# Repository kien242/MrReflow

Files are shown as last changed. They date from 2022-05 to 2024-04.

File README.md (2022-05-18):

Invent This, Invent That

# ESPReflow
Firmware for SMT reflow controller.

> **!!! WARNING: This project deals with mains power and high current !!!**
> Please be careful if you wish to replicate any of it's functionality and never work on a PCB or any open wires that are connected to the mains !
> Author has no responsibility for your safety and wellbeing, so please take care of yourself.

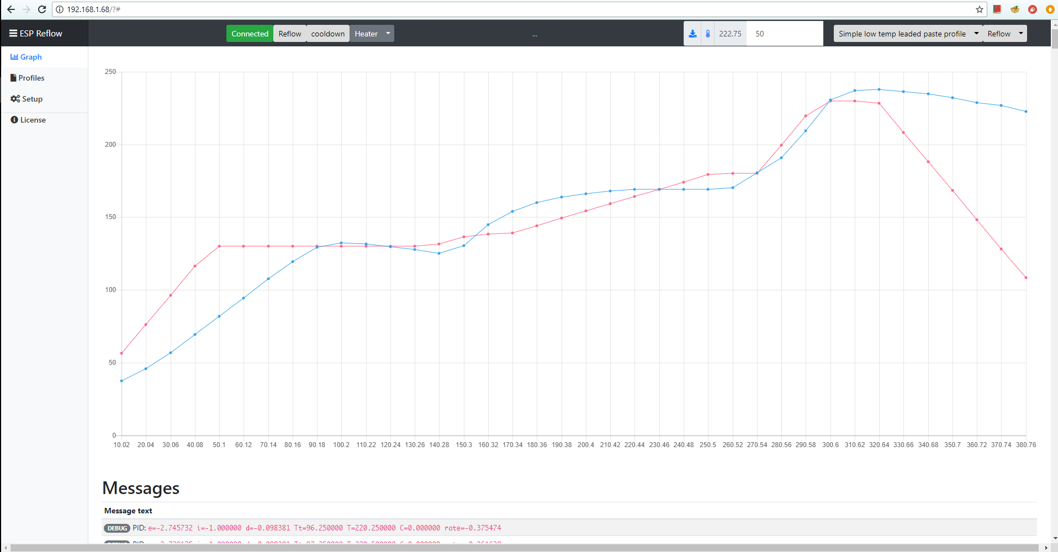
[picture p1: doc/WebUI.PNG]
ESPReflow Web UI


# How it works
The purpose of this project is to control a heater of any sort to facilitate SMT reflow soldering utilizing a predefined temperature profile. Control of the heater is performed by ESP8266 or ESP32 chip via Web UI over WiFi.

To achieve that, readings from a thermocouple are used for closed loop temperature control of the target board. The controller does it's best to follow a preconfigured temperature profile for a particular SMT soldering. Of course the accuracy of the temperature profile achieved is heavily dependant on the thermal properties of the heating element, environment, the boards, etc. The controller tries to compensate for that by the means of a PID controller which has to be tuned to a particular setup.

## Prototype Hardware

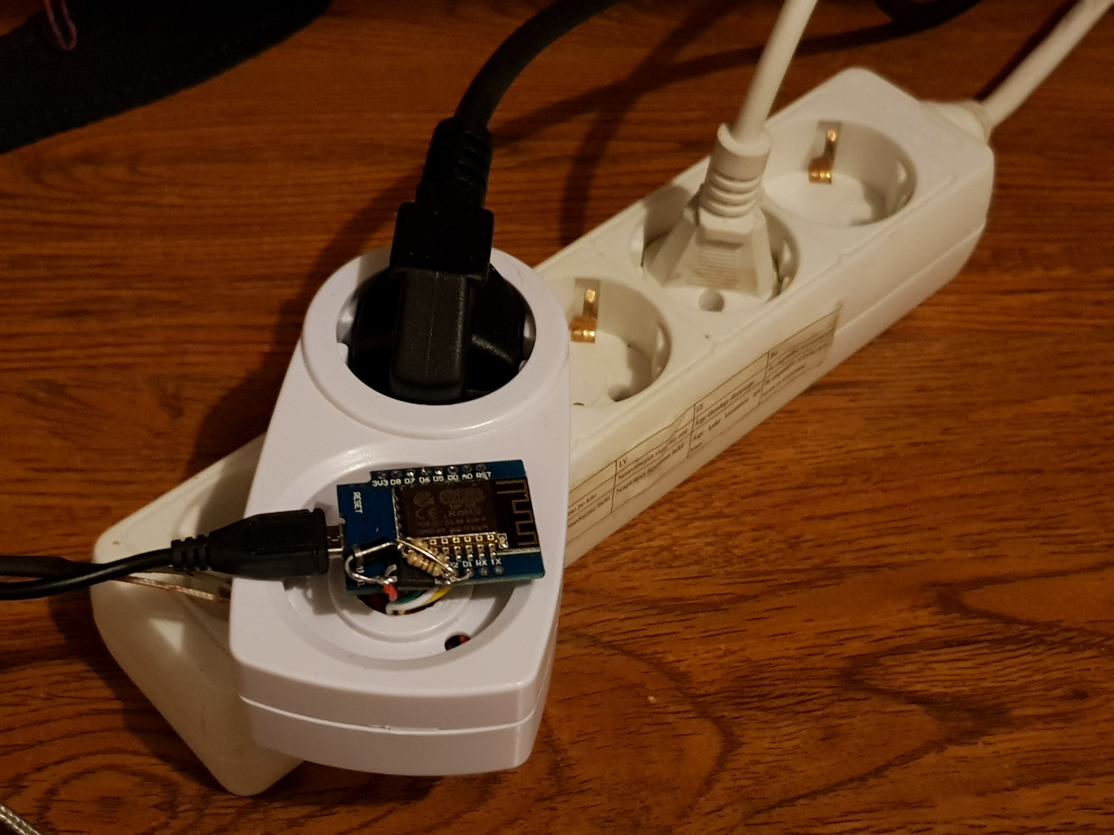
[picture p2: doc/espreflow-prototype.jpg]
ESPReflow prototype


* Some generic mechanical timer enclosure is used for the plug, socket and, well, enclosure.
* max6675 is used for interfacing with a thermocouple.
* Generic optopair is used for controlling a 10A relay (for the prototype).
* Weemos D1 mini is used for the brains.
* Some cheap 1200W IR Hotplate is used for the load
* a peace of prototype board is used for dummy board

## Schematics

ESReflow schematics
rev 1.0 board

EasyEDA project page: https://easyeda.com/andrius.mikonis/ESPReflow-f4c523157afa47758e46728248cdb19b

## Assigned pins

```
#define thermoDO 13 // D7
#define thermoCS 12 // D6
#define thermoCLK 14 // D5
#define relay 4 // D2
```

## Building
### Angular Frontend

Angular front end source is in `web-src-angular` folder and should be built using nodejs. After binaries are built,
they should be gzipped and copied into `data/web` folder before uploading.

### Backend

Backend is implemented using Arduino SDK and built using PlatformIO. Before building, please copy `src/sample_wificonfig.h`
to `src/wificonfig.h` and add default Wireless Network configuration. You will be able to edit this configuration via Web interface later.

## Modes of operation
### Reflow

In this mode the controller will perform reflow algorithm following selected reflow profile.
Controller will turn off the mode once the temperature reaches safe values after the profile is completed.

### Calibrate

In this mode a selected calibration algorithm will be used to find optimal PID controller parameters.
Controller will turn off the mode once the temperature reaches safe values after the calibration is completed.

### Keep Target

In this mode the controller will reach and maintain target temperature. Useful to check PID configuration. `default` PID configuration will be used in this mode.

# Flashing

There are two ways to flash the controller - via serial or via OTA.

## Serial

Find `RX/TX/GND` pins on the board, connect your serial adapter and flash either Arduino, PlatformIO or whatever flasher you like.
**NOTE: `RX/TX` pins are NOT 5V tolerant. Please use 3.3V serial adapter or level shifter from 5V**

## OTA

When the controller is first turned on it creates an AP with the name `ESPReflow` and the ip address `192.168.4.1`. Connect to the controller, wait until the page loads and go to `Setup`, enter WiFi SSID and credentials. Save the configuration and reboot.
After this is done it will connect to the specified WiFi AP and will register it's own domain as `ReflowControl.local`.
Tuning and operation of the controller can then be done.

## OTA HTTP upload

You can upload a firmware binary using `Setup` - just upload the new firmware on the WebUI.

# Usage

## Connect your hotplate/oven

### Hot plate

### IR Hot plate
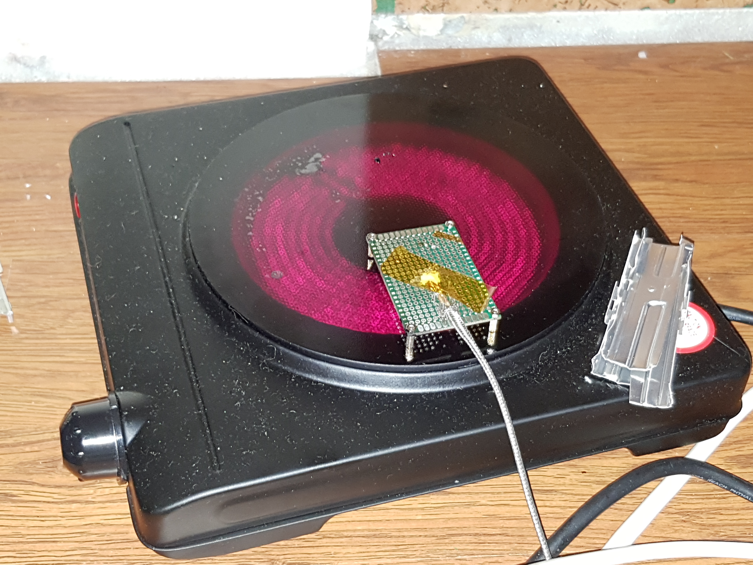
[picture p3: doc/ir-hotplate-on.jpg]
IR hotplate in action


## K-type thermal probe

Thermocouple must be placed on a dummy board, that would approximately resemble the target boards. For best results that board must be placed in a similar matter as the target board. Furthermore, since hotplates do not heat evenly(even some ovens), care must be taken to allow dummy board be heated the same way as the target board(i.e. it must be placed approximately the same distance and orientation as the target board in respect to the heating elements). Otherwise you may burn the target board.

## PID tuning

PID tuning must be done for every heating device individually. You can do it by trial and error, or ESPReflow can do it for you. There are several auto tuning algorithms available (a slightly modified [PID-aTune library fork](https://github.com/t0mpr1c3/Arduino-PID-AutoTune-Library)):

*		ZIEGLER_NICHOLS_PI
*		ZIEGLER_NICHOLS_PID
*		TYREUS_LUYBEN_PI
*		TYREUS_LUYBEN_PID
*		CIANCONE_MARLIN_PI
*		CIANCONE_MARLIN_PID
*		AMIGOF_PI
*		PESSEN_INTEGRAL_PID
*		SOME_OVERSHOOT_PID
*		NO_OVERSHOOT_PID"

## Reflow profile

# Problem Solving

## Unable to properly tune IR Hot plate

During development a cheap IR hot plate was used. I found that if you place your temperature probe and the boards on the hot plate itself it would be very hard to control the temperature of the board properly. So, I used aluminium raisers, that raise the board around 5-10mm from the hot plate so that IR radiation would heat the boards instead of the glass plate.

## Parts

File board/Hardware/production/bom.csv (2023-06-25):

Designator | Footprint | Quantity | Value | LCSC Part #
C1, C4 | 0603 | 2 | 1u
C10, C6, C8, C9 | 0603 | 4 | 100n
C11, C7 | 0603 | 2 | 10n
C12, C15 | 0603 | 2 | 10uF
C13, C14 | 0603 | 2 | 100nF
C2, C3 | CP_Elec_4x5.4 | 2 | 10u
C5 | CP_EIA-3216-12_Kemet-S_Pad1.58x1.35mm_HandSolder | 1
D1 | D_SOD-123 | 1 | 1N5819
H1, H2, H3, H4 | MountingHole_3.2mm_M3_Pad | 4 | MountingHole_Pad
J1 | TerminalBlock_4Ucon_1x02_P3.50mm_Horizontal | 1 | VIN
J2 | USB-C-16pin-hight-v2 | 1
J3 | 1.14_TFT_Display | 1 | Conn_01x08
J4 | TerminalBlock_4Ucon_1x02_P3.50mm_Horizontal | 1 | TC1
J5 | TerminalBlock_4Ucon_1x02_P3.50mm_Horizontal | 1 | TC2
J6 | TerminalBlock_4Ucon_1x02_P3.50mm_Horizontal | 1 | SSR1
J7 | TerminalBlock_4Ucon_1x02_P3.50mm_Horizontal | 1 | SSR2
J8 | TerminalBlock_4Ucon_1x02_P3.50mm_Horizontal | 1 | SSR3
JP1, JP2 | SolderJumper-3_P2.0mm_Open_TrianglePad1.0x1.5mm_NumberLabels | 2
L1, L2, L3, L4 | 0603 | 4 | ferrite
LS1 | Buzzer_12x9.5RM7.6 | 1 | Speaker
Q1 | SOT-23_Handsoldering | 1 | AO3407
Q2, Q3, Q4 | TO-252-2 | 3 | IRLR2905Z
Q5 | SOT-23_Handsoldering | 1 | BSS138
Q7, Q8 | SOT-23_Handsoldering | 2 | 2N3904
R1 | 0603 | 1 | 100K
R10, R11 | 0603 | 2 | R_Small
R12 | 0603 | 1 | ??
R13, R14, R15, R16, R2, R24, R25, R3, R4, R5, R6, R7 | 0603 | 12 | 10k
R17, R18 | 0603 | 2 | 5k1
R19 | 0603 | 1 | 22k1
R20 | 0603 | 1 | 47k5
R21, R23 | 0603 | 2 | 22r
R22 | 0603 | 1 | 1k
R8, R9 | 0603 | 2 | 5k
SW1, SW2 | SW_PUSH_6mm_H13mm | 2
SW3 | SW_SPST_B3U-1000P | 1 | SW_RESET
SW4 | SW_SPST_B3U-1000P | 1 | SW_BOOT
SW5 | RotaryEncoder_Alps_EC11E-Switch_Vertical_H20mm | 1
U1 | YAAJ_DCDC_StepDown_LM2596 | 1 | YAAJ_DCDC_StepDown_LM2596
U2 | SOT-223-3_TabPin2 | 1 | NCP1117-3.3_SOT223
U3 | QFN-28-1EP_5x5mm_P0.5mm_EP3.35x3.35mm_ThermalVias | 1 | CP2102-GM
U4, U6 | SOIC-8_3.9x4.9mm_P1.27mm | 2 | MAX31855KASA
U5 | ESP32-WROOM-32 | 1 | ESP32-WROOM-32

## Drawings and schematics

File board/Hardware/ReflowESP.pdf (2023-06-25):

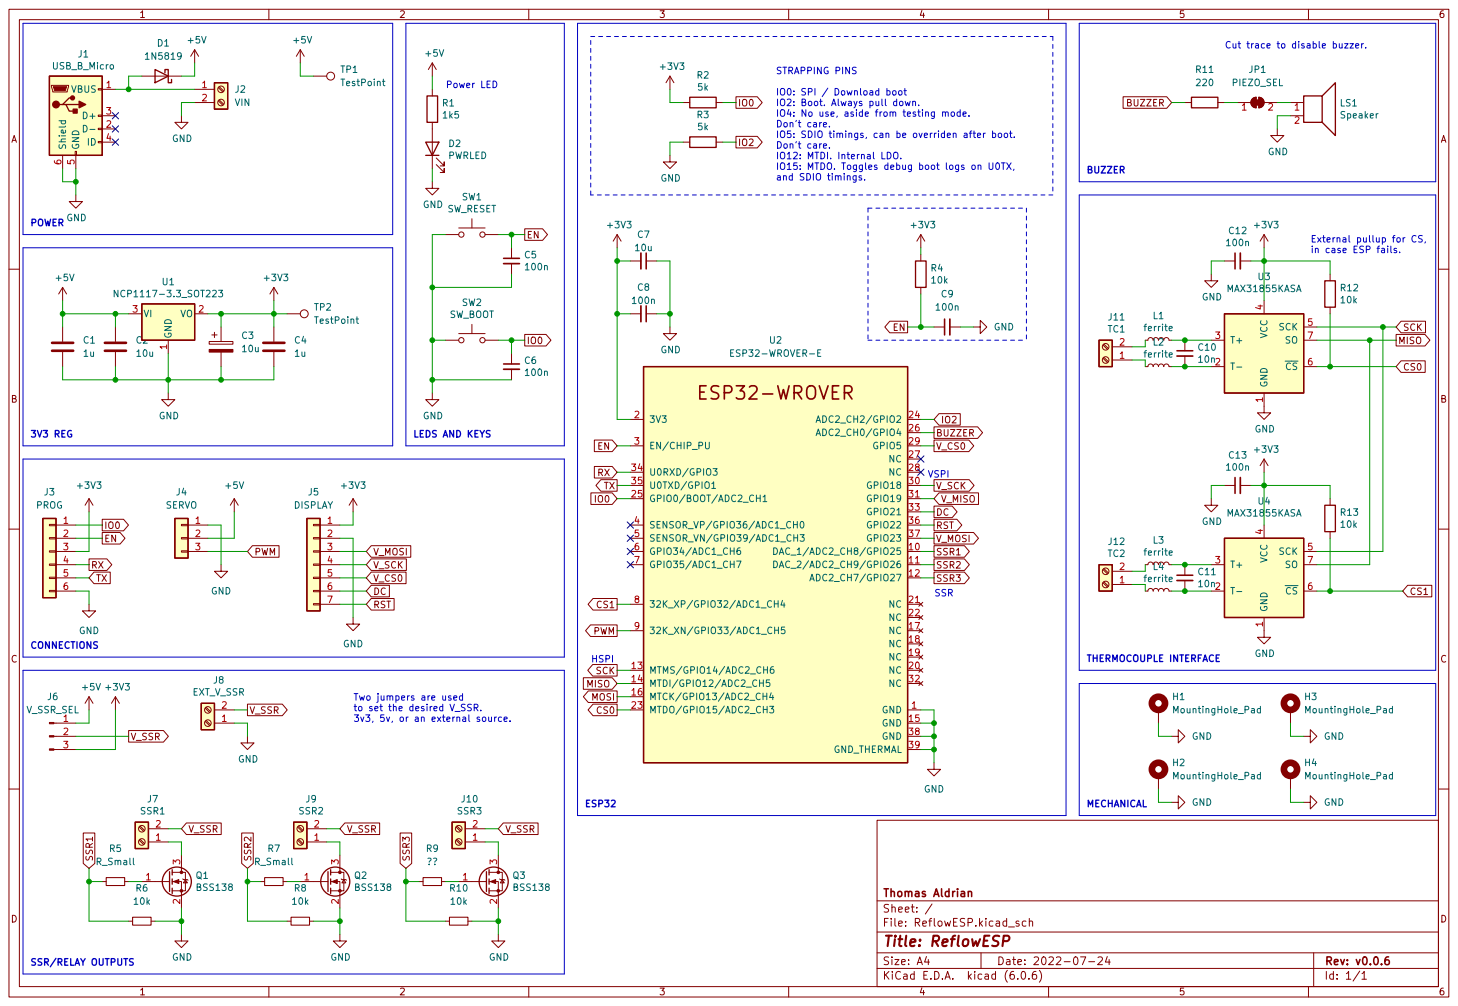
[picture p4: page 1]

Cut trace to disable buzzer. BUZZER
JP1 PIEZO_SEL GND
LS1 Speaker GND

IO0: SPI / Download boot
IO2: Boot. Always pull down.
IO4: No use, aside from testing mode. Don't care.

IO5: SDIO timings, can be overriden after boot. Don't care.

IO12: MTDI. Internal LDO.
IO15: MTDO. Toggles debug boot logs on U0TX,

External pullup for CS,

1 VO 2 VI 3 U1 NCP1117-3.3_SOT223 GND GND þÿESP32--WROVER

to set the desired V_SSR. 3v3, 5v, or an external source. CONNECTIONS

Two jumpers are used

File: ReflowESP.kicad_sch Sheet: / Thomas Aldrian

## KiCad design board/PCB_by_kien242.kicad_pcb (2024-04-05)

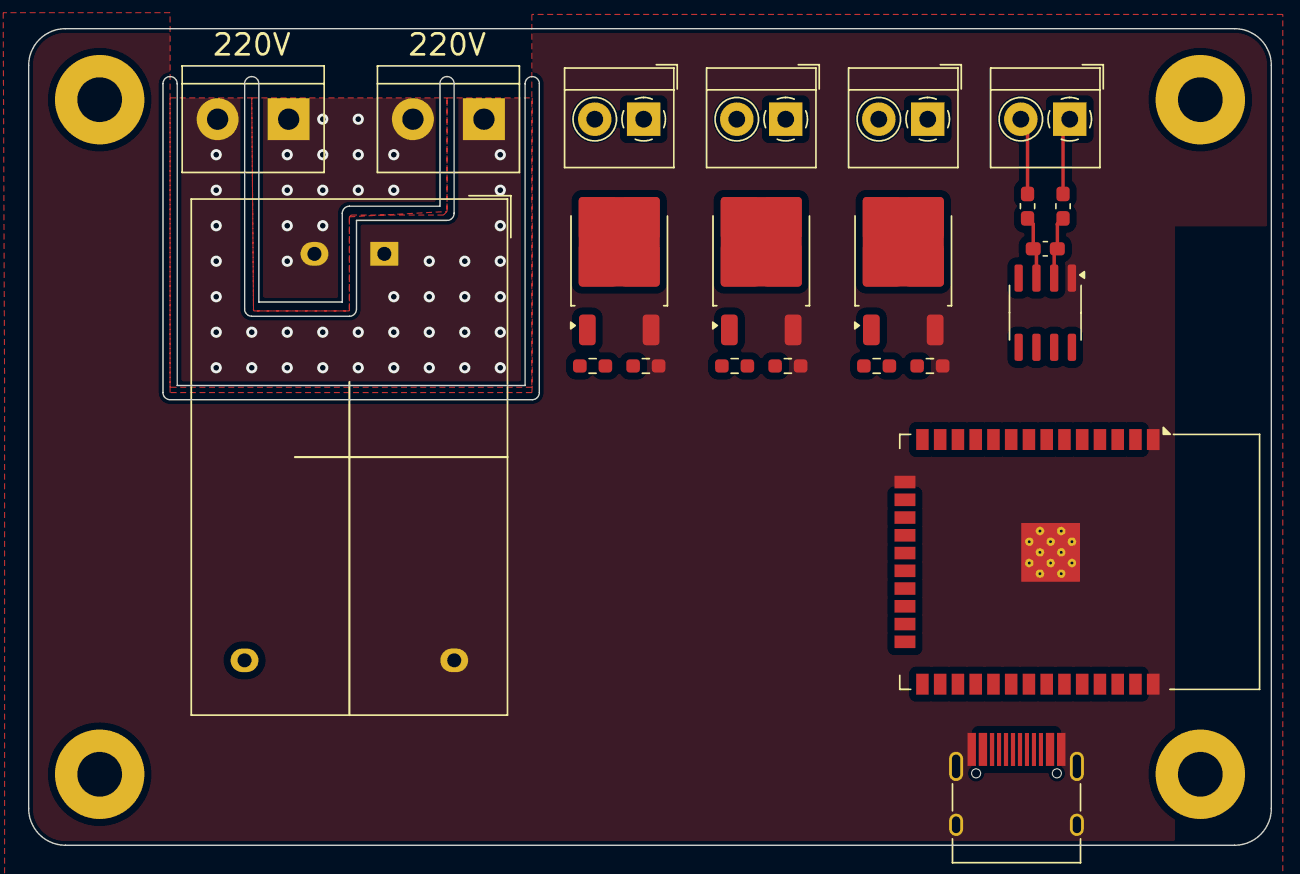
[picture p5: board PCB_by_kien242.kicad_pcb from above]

Board: 2 copper layers, 88.9 x 58.4 mm, 26 parts (0 on the bottom side), 24 nets.

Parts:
C11: 10n; C_0603_1608Metric_Pad1.08x0.95mm_HandSolder
H1, H2, H3, H4: MountingHole_Pad; MountingHole_3.2mm_M3_Pad
J1, J3: VIN; TerminalBlock_bornier-2_P5.08mm
J2: USB-C-16pin-hight-v2
J4: TC1; TerminalBlock_4Ucon_1x02_P3.50mm_Horizontal
J6: SSR1; TerminalBlock_4Ucon_1x02_P3.50mm_Horizontal
J7: SSR2; TerminalBlock_4Ucon_1x02_P3.50mm_Horizontal
J8: SSR3; TerminalBlock_4Ucon_1x02_P3.50mm_Horizontal
L1, L2: ferrite; L_0603_1608Metric_Pad1.05x0.95mm_HandSolder
PS1: HLK-PM05; Converter_ACDC_Hi-Link_HLK-PMxx
Q4, Q5, Q6: IRLR2905Z; TO-252-2
R19, R20: R_Small; R_0603_1608Metric_Pad0.98x0.95mm_HandSolder
R21: ??; R_0603_1608Metric_Pad0.98x0.95mm_HandSolder
R22, R23, R24: 10k; R_0603_1608Metric_Pad0.98x0.95mm_HandSolder
U4: MAX31855KASA; SOIC-8_3.9x4.9mm_P1.27mm
U5: ESP32-WROOM-32

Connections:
+3.3V: U4.4 (VCC), U5.2 (VDD)
CS0: U4.6 (~CS), U5.23 (IO15)
D+: J2.A6 (D+), J2.B6 (D+)
D-: J2.A7 (D-), J2.B7 (D-)
GND: J2.A1 (GND), J2.A12 (GND), J2.B1 (GND), J2.B12 (GND), J2.S1 (SHIELD), PS1.3 (-Vout), Q4.3 (S), Q5.3 (S), Q6.3 (S), R22.2, R23.2, R24.2, U4.1 (GND), U5.1 (GND), U5.15 (GND), U5.38 (GND), U5.39 (GND)
MISO: U4.7 (SO), U5.14 (IO12)
unnamed: J1.1, J3.2, PS1.1 (AC/L)
unnamed: J1.2, J3.1, PS1.2 (AC/N)
unnamed: J4.1, L2.2
unnamed: J4.2, L1.2
unnamed: J6.1, Q4.2 (D)
unnamed: J7.1, Q5.2 (D)
unnamed: J8.1, Q6.2 (D)
unnamed: Q4.1 (G), R19.2
unnamed: Q5.1 (G), R20.2
unnamed: Q6.1 (G), R21.2
unnamed: C11.1, L1.1, U4.3 (T+)
unnamed: C11.2, L2.1, U4.2 (T-)
SCK: U4.5 (SCK), U5.13 (IO14)
SSR1: R21.1, R24.1, U5.10 (IO25)
SSR2: R20.1, R23.1, U5.11 (IO26)
SSR3: R19.1, R22.1, U5.12 (IO27)
VBUS: J2.A4 (VBUS), J2.A9 (VBUS), J2.B4 (VBUS), J2.B9 (VBUS)
V_SSR: J6.2, J7.2, J8.2, PS1.4 (+Vout)

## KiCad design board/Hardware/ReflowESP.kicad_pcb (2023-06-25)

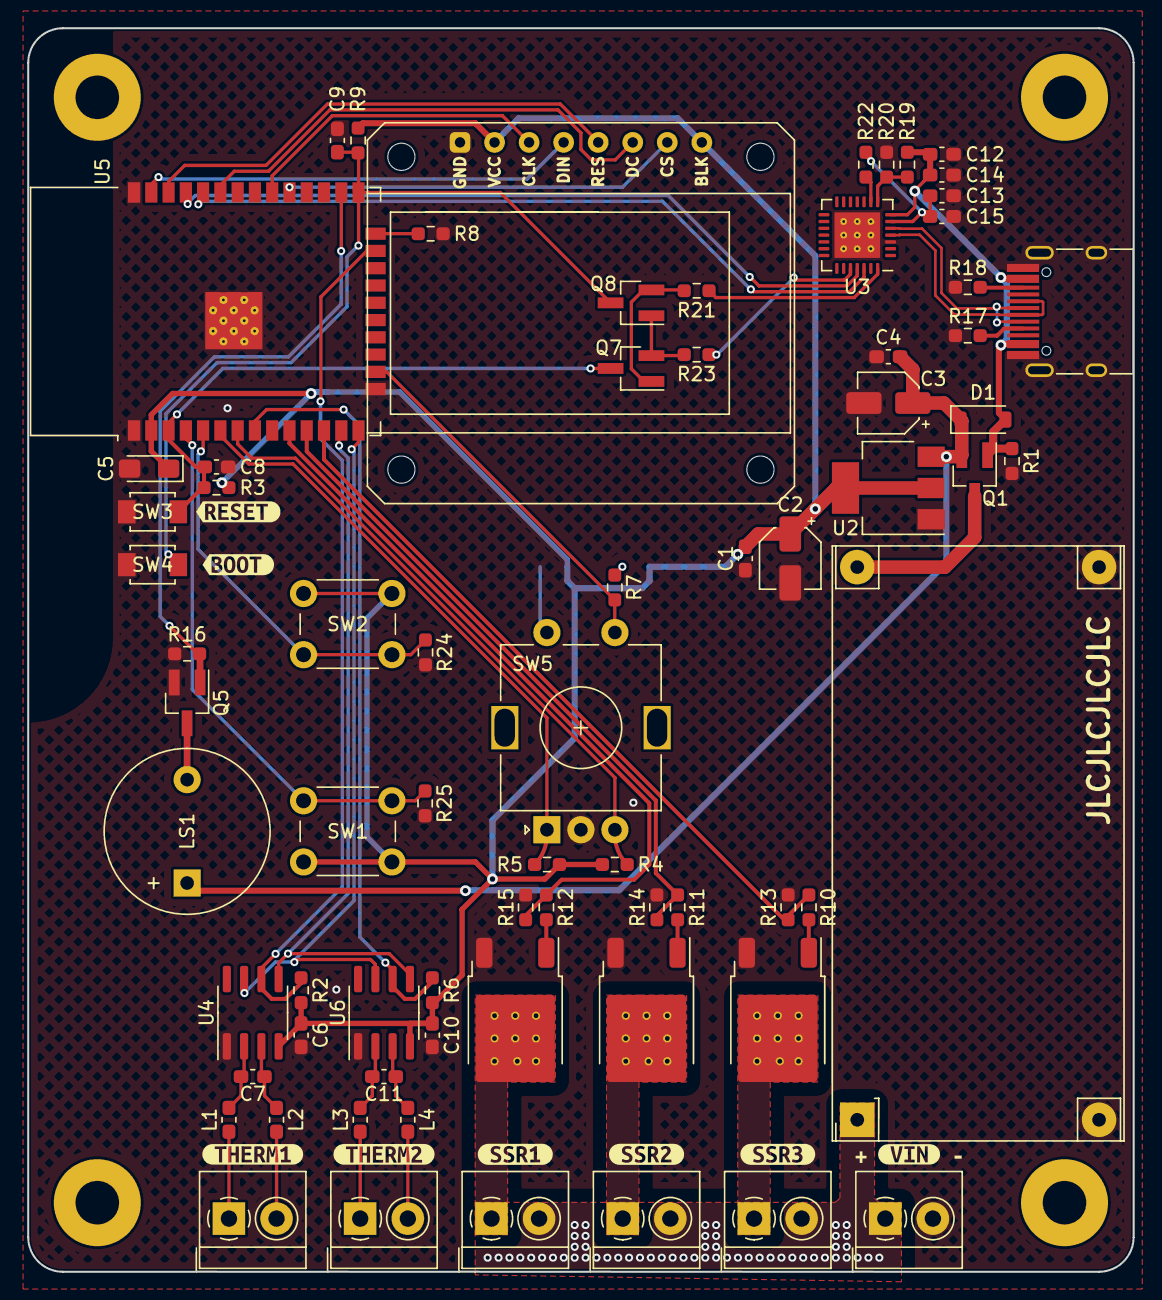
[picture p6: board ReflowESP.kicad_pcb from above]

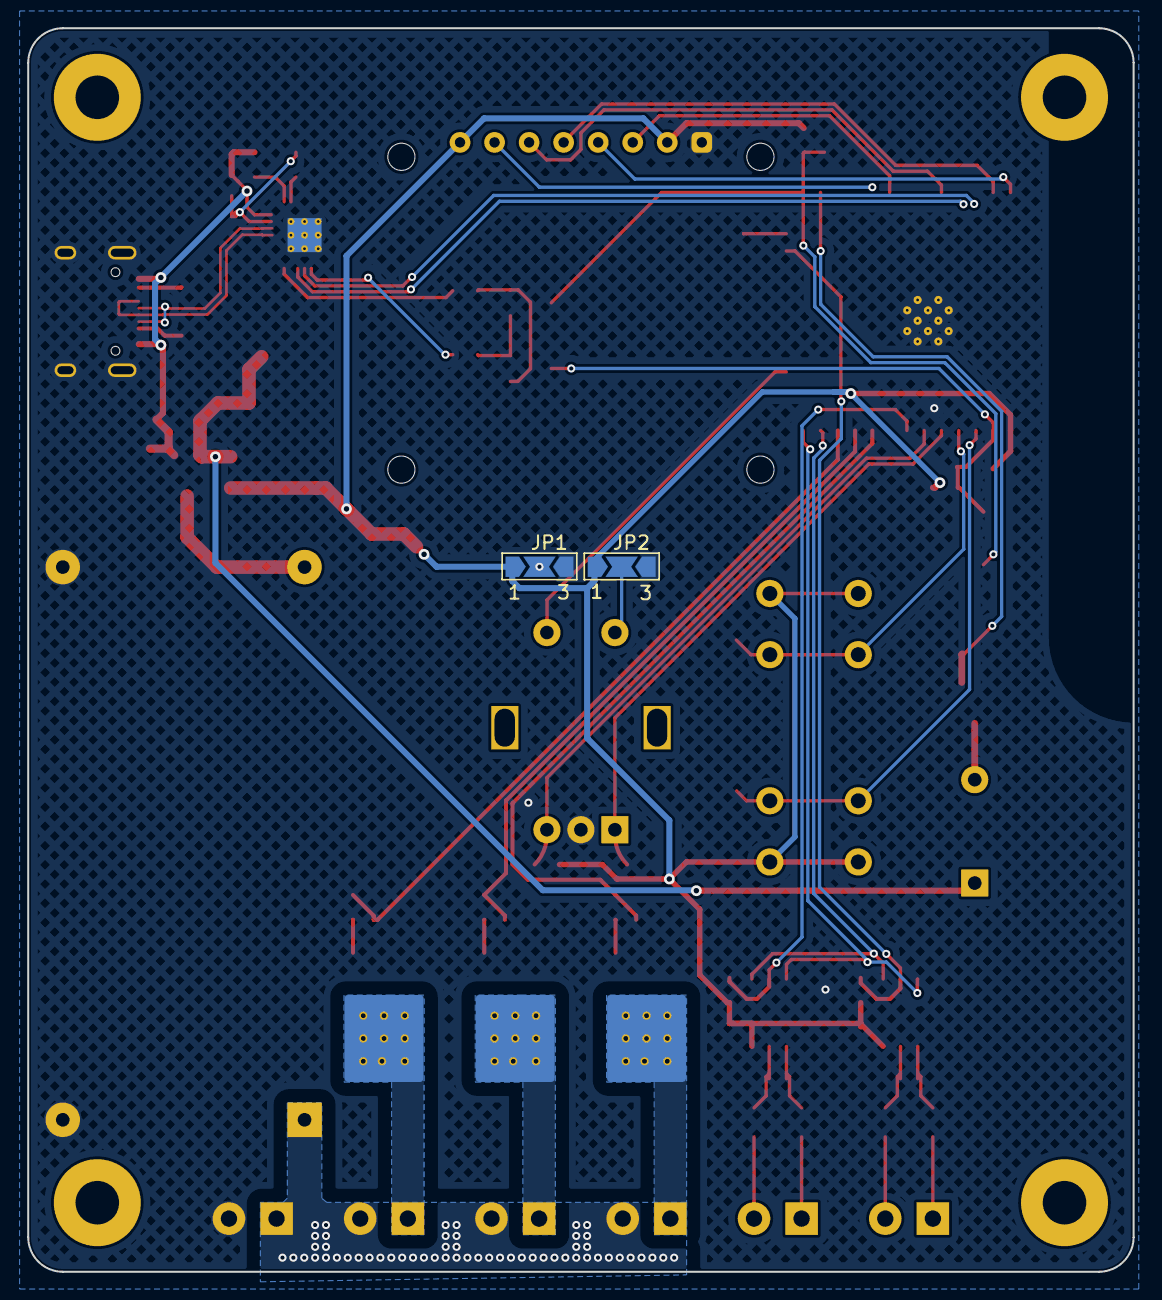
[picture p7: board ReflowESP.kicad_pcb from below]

Board: 2 copper layers, 81.3 x 91.4 mm, 88 parts (2 on the bottom side), 57 nets.

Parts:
C1, C4: 1u; C_0603_1608Metric_Pad1.08x0.95mm_HandSolder
C2, C3: 10u; CP_Elec_4x5.4
C5: CP_EIA-3216-12_Kemet-S_Pad1.58x1.35mm_HandSolder
C6, C8, C9, C10: 100n; C_0603_1608Metric_Pad1.08x0.95mm_HandSolder
C7, C11: 10n; C_0603_1608Metric_Pad1.08x0.95mm_HandSolder
C12, C15: 10uF; C_0603_1608Metric_Pad1.08x0.95mm_HandSolder
C13, C14: 100nF; C_0603_1608Metric_Pad1.08x0.95mm_HandSolder
D1: 1N5819; D_SOD-123
H1, H2, H3, H4: MountingHole_Pad; MountingHole_3.2mm_M3_Pad
J1: VIN; TerminalBlock_4Ucon_1x02_P3.50mm_Horizontal
J2: USB-C-16pin-hight-v2
J3: Conn_01x08; 1.14_TFT_Display
J4: TC1; TerminalBlock_4Ucon_1x02_P3.50mm_Horizontal
J5: TC2; TerminalBlock_4Ucon_1x02_P3.50mm_Horizontal
J6: SSR1; TerminalBlock_4Ucon_1x02_P3.50mm_Horizontal
J7: SSR2; TerminalBlock_4Ucon_1x02_P3.50mm_Horizontal
J8: SSR3; TerminalBlock_4Ucon_1x02_P3.50mm_Horizontal
JP1, JP2: SolderJumper-3_P2.0mm_Open_TrianglePad1.0x1.5mm_NumberLabels
L1, L2, L3, L4: ferrite; L_0603_1608Metric_Pad1.05x0.95mm_HandSolder
LS1: Speaker; Buzzer_12x9.5RM7.6
Q1: AO3407; SOT-23_Handsoldering
Q2, Q3, Q4: IRLR2905Z; TO-252-2
Q5: BSS138; SOT-23_Handsoldering
Q7, Q8: 2N3904; SOT-23_Handsoldering
R1: 100K; R_0603_1608Metric_Pad0.98x0.95mm_HandSolder
R2, R3, R4, R5, R6, R7, R13, R14, R15, R16, R24, R25: 10k; R_0603_1608Metric_Pad0.98x0.95mm_HandSolder
R8, R9: 5k; R_0603_1608Metric_Pad0.98x0.95mm_HandSolder
R10, R11: R_Small; R_0603_1608Metric_Pad0.98x0.95mm_HandSolder
R12: ??; R_0603_1608Metric_Pad0.98x0.95mm_HandSolder
R17, R18: 5k1; R_0603_1608Metric_Pad0.98x0.95mm_HandSolder
R19: 22k1; R_0603_1608Metric_Pad0.98x0.95mm_HandSolder
R20: 47k5; R_0603_1608Metric_Pad0.98x0.95mm_HandSolder
R21, R23: 22r; R_0603_1608Metric_Pad0.98x0.95mm_HandSolder
R22: 1k; R_0603_1608Metric_Pad0.98x0.95mm_HandSolder
SW1, SW2: SW_PUSH_6mm_H13mm
SW3: SW_RESET; SW_SPST_B3U-1000P
SW4: SW_BOOT; SW_SPST_B3U-1000P
SW5: RotaryEncoder_Alps_EC11E-Switch_Vertical_H20mm
U1: YAAJ_DCDC_StepDown_LM2596
U2: NCP1117-3.3_SOT223; SOT-223-3_TabPin2
U3: CP2102-GM; QFN-28-1EP_5x5mm_P0.5mm_EP3.35x3.35mm_ThermalVias
U4, U6: MAX31855KASA; SOIC-8_3.9x4.9mm_P1.27mm
U5: ESP32-WROOM-32
kibuzzard-6465B1A6: G***; kibuzzard-6465B1A6
kibuzzard-6465B1D4: G***; kibuzzard-6465B1D4
kibuzzard-6465B1DF: G***; kibuzzard-6465B1DF
kibuzzard-6465FE6A: G***; kibuzzard-6465FE6A
kibuzzard-6465FE70: G***; kibuzzard-6465FE70
kibuzzard-64660A1B: G***; kibuzzard-64660A1B
kibuzzard-64660A10: G***; kibuzzard-64660A10
kibuzzard-64660AB6: G***; kibuzzard-64660AB6
kibuzzard-64660ABC: G***; kibuzzard-64660ABC
kibuzzard-646609E4: G***; kibuzzard-646609E4

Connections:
+3.3V: C1.2, C2.1, C5.1, C6.1, C10.1, J3.2, J3.8, JP1.1 (A), JP2.1 (A), R2.2, R3.1, R4.1, R5.2, R6.2, R9.1, SW1.2, SW2.1, U2.2 (VO), U4.4 (VCC), U5.2 (VDD), U6.4 (VCC)
+5V: C3.1, C4.2, D1.1 (K), LS1.1, Q1.2 (S), U2.3 (VI)
BUZZER: Q5.1 (G), R16.2, U5.26 (IO4)
CS0: R2.1, U4.6 (~CS), U5.23 (IO15)
CS1: R6.1, U5.8 (IO32), U6.6 (~CS)
D+: J2.A6 (D+), J2.B6 (D+), U3.4 (D+)
D-: J2.A7 (D-), J2.B7 (D-), U3.5 (D–)
DC: J3.6, U5.33 (IO21)
DTR: R21.1, U3.28 (~DTR)
EN: C8.1, Q7.3 (C), R3.2, SW3.2, U5.3 (EN)
GND: C1.1, C2.2, C3.2, C4.1, C5.2, C6.2, C8.2, C9.2, C10.2, C12.1, C13.2, C14.2, C15.1, J1.2, J2.A1 (GND), J2.A12 (GND), J2.B1 (GND), J2.B12 (GND), J2.S1 (SHIELD), J3.1, JP1.3 (B), JP2.3 (B), Q2.3 (S), Q3.3 (S), Q4.3 (S), Q5.2 (S), R1.2, R8.2, R13.2, R14.2, R15.2, R16.1, R17.1, R18.1, R20.2, R24.2, R25.2, SW3.1, SW4.1, SW5.C, U1.2 (GND), U1.3 (GND), U2.1 (GND), U3.3 (GND), U3.29 (GND), U4.1 (GND), U5.1 (GND), U5.15 (GND), U5.38 (GND), U5.39 (GND), U6.1 (GND)
IO0: C9.1, Q8.3 (C), R9.2, SW4.2, U5.25 (IO0)
IO2: R8.1, U5.24 (IO2)
MISO: U4.7 (SO), U5.14 (IO12), U6.7 (SO)
unnamed: J2.A5 (CC1), R17.2
unnamed: J2.B5 (CC2), R18.2
unnamed: J4.1, L1.1
unnamed: J4.2, L2.2
unnamed: J5.1, L3.1
unnamed: J5.2, L4.2
unnamed: J6.1, Q2.2 (D)
unnamed: J7.1, Q3.2 (D)
unnamed: J8.1, Q4.2 (D)
unnamed: JP1.2 (C), R7.1
unnamed: JP2.2 (C), SW5.S1
unnamed: Q1.3 (D), U1.4 (Vout)
unnamed: Q2.1 (G), R10.2
unnamed: Q3.1 (G), R11.2
unnamed: Q4.1 (G), R12.2
unnamed: LS1.2, Q5.3 (D)
unnamed: Q7.1 (B), Q8.2 (E), R21.2
unnamed: Q7.2 (E), Q8.1 (B), R23.2
unnamed: R22.2, U3.9 (~RST)
unnamed: C7.1, L2.1, U4.3 (T+)
unnamed: C7.2, L1.2, U4.2 (T-)
unnamed: C11.1, L4.1, U6.3 (T+)
unnamed: C11.2, L3.2, U6.2 (T-)
RE_A: R5.1, SW5.A, U5.6 (IO34)
RE_B: R4.2, SW5.B, U5.7 (IO35)
RE_SW: R7.2, SW5.S2, U5.16 (IO13)
RST: J3.5, U5.36 (IO22)
RTS: R23.1, U3.24 (~RTS)
RX: U3.26 (TXD), U5.34 (RXD0/IO3)
SCK: U4.5 (SCK), U5.13 (IO14), U6.5 (SCK)
SSR1: R12.1, R15.1, U5.10 (IO25)
SSR2: R11.1, R14.1, U5.11 (IO26)
SSR3: R10.1, R13.1, U5.12 (IO27)
SW_1: R25.1, SW1.1, U5.4 (SENSOR_VP)
SW_2: R24.1, SW2.2, U5.5 (SENSOR_VN)
TX: U3.25 (RXD), U5.35 (TXD0/IO1)
VBUS: C12.2, C14.1, D1.2 (A), J2.A4 (VBUS), J2.A9 (VBUS), J2.B4 (VBUS), J2.B9 (VBUS), Q1.1 (G), R1.1, R19.1, U3.7 (REGIN)
VBUSREF: R19.2, R20.1, U3.8 (VBUS)
VCC: C13.1, C15.2, R22.1, U3.6 (VDD)
V_CS0: J3.7, U5.29 (IO5)
V_MOSI: J3.4, U5.37 (IO23)
V_SCK: J3.3, U5.30 (IO18)
V_SSR: J1.1, J6.2, J7.2, J8.2, U1.1 (Vin)

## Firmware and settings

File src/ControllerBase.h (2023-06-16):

/**
 *  Copyright (C) 2018  foxis (Andrius Mikonis <andrius.mikonis@gmail.com>)
 *
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
 *  You should have received a copy of the GNU General Public License
 *  along with this program.  If not, see <http://www.gnu.org/licenses/>.
 **/

#ifndef CONTROLLER_BASE_H
#define CONTROLLER_BASE_H

#include <PID_v10.h>
#include <SPI.h>
#include "Config.h"
#include <PID_AutoTune_v0.h> // https://github.com/t0mpr1c3/Arduino-PID-AutoTune-Library
#include <Adafruit_GFX.h>
#include <Adafruit_SSD1306.h>


#define thermoDO 12
#define thermoCS 15
#define thermoCLK 14

#define DEFAULT_TARGET 60
#define MAX_ON_TIME 1000 * 60 * 15
#define MAX_TEMPERATURE 400
#define MIN_TEMP_RISE_TIME 1000 * 120
#define MIN_TEMP_RISE 10
#define CONTROL_HYSTERISIS .01
#define DEFAULT_TEMP_RISE_AFTER_OFF 30.0
#define SAFE_TEMPERATURE 50
#define CAL_HEATUP_TEMPERATURE 90
#define DEFAULT_CAL_ITERATIONS 3
#define WATCHDOG_TIMEOUT 30000

#include <max6675.h>


#define CB_GETTER(T, name) \
  virtual T name() { return _##name; }
#define CB_SETTER(T, name) \
  virtual T name(T name)   \
  {                        \
    T pa##name = _##name;  \
    _##name = name;        \
    return pa##name;       \
  }

class ControllerBase
{
public:
  typedef float Temperature_t;
  typedef enum
  {
    UNKNOWN = -100,
    INIT = -2,
    ERROR_OFF = -1,
    OFF = 0,
    ON = 1,
    TARGET_PID = 2,
    CALIBRATE = 3,
    REFLOW = 4,
    CALIBRATE_COOL = 5,
    REFLOW_COOL = 6,
  } MODE_t;

  typedef std::function<void(const char *message)> THandlerFunction_Message;
  typedef std::function<void(MODE_t last, MODE_t current)> THandlerFunction_Mode;
  typedef std::function<void(const char *stage, float target)> THandlerFunction_Stage;
  typedef std::function<void(bool heater)> THandlerFunction_Heater;
  typedef std::function<void(const std::vector<Temperature_t> &readings, unsigned long now)> THandlerFunction_ReadingsReport;

private:
  std::vector<Temperature_t> _readings;
  double _temperature;
  double _target;
  double _CALIBRATE_max_temperature;
  double _target_control;
  double _avg_rate;
  unsigned long _last_heater_on;

  unsigned long _now;

  double _calP, _calD, _calI;

protected:
  Config &config;

private:
  PID pidTemperature;
  PID_ATune aTune;

public:
  ControllerBase(Config &cfg, Adafruit_SSD1306 &display);
  Adafruit_SSD1306 display;
  String line1 = "";
  String line2 = "";
  String line3 = "";

  void draw()
  {
    display.clearDisplay();
    display.setCursor(0, 0);
    display.setTextSize(1);
    display.println(line1);

    display.setCursor(0, 12);
    display.setTextSize(4);
    display.println(line2);

    if (line3.length() > 10)
    {
      display.setTextSize(1);
    }
    else
    {
      display.setTextSize(2);
    }
    display.setCursor(0, 64 - 16);

    display.println(line3);

    if (_heater)
    {
      display.fillCircle(120, 7, 5, 1);
    }
    else
    {
      display.drawCircle(120, 7, 5, 1);
    }

    int state = millis() / 100 % 4;
    display.setCursor(118, 54);
    if (state == 0)
    {
      display.println("-");
    }
    if (state == 1)
    {
      display.println("\\");
    }
    if (state == 2)
    {
      display.println("|");
    }
    if (state == 3)
    {
      display.println("/");
    }
    display.display();
  }

  virtual const char *name() = 0;

  virtual void loop(unsigned long now);

  CB_GETTER(double, target)
  CB_SETTER(double, target)

  CB_GETTER(double, temperature)

  CB_GETTER(std::vector<Temperature_t> &, readings)

  CB_GETTER(MODE_t, mode)
  CB_SETTER(MODE_t, mode)

  CB_GETTER(bool, heater)

  CB_GETTER(bool, locked)
  CB_SETTER(bool, locked)

  CB_GETTER(unsigned long, start_time)

  CB_SETTER(const String &, profile)
  CB_GETTER(const String &, profile)

  CB_SETTER(double, avg_rate)
  CB_GETTER(double, avg_rate)

  CB_GETTER(const String &, stage)

  CB_SETTER(THandlerFunction_Message, onMessage)
  CB_SETTER(THandlerFunction_Mode, onMode)
  CB_SETTER(THandlerFunction_Heater, onHeater)
  CB_SETTER(THandlerFunction_Stage, onStage)
  CB_SETTER(THandlerFunction_ReadingsReport, onReadingsReport)

  PID &setPID(float P, float I, float D);

  PID &setPID(const String &name);

  void resetPID();

  String calibrationString();

  const char *translate_mode(MODE_t mode = UNKNOWN);

  Temperature_t temperature_to_log(float t);

  float log_to_temperature(Temperature_t t);

  float measure_temperature(unsigned long now);
  unsigned long elapsed(unsigned long now);

private:
  MAX6675 thermocouple;
  bool _locked;
  bool _heater;
  bool _last_heater;
  unsigned long last_m;
  unsigned long last_log_m;
  unsigned long _start_time;

  void _setPinMode(int pin, int mode);
  void _setPinValue(int pin, int value);

  float _read_temperature();

  MODE_t _mode;
  MODE_t _last_mode;

  String _profile;
  String _stage;

protected:
  CB_SETTER(const String &, stage)
  CB_SETTER(double, temperature)

  THandlerFunction_Message _onMessage;
  THandlerFunction_Mode _onMode;
  THandlerFunction_Heater _onHeater;
  THandlerFunction_Stage _onStage;
  THandlerFunction_ReadingsReport _onReadingsReport;

  void callMessage(const char *format, ...);

  void reportReadings(unsigned long now);

  virtual void handle_mode(unsigned long now);

  virtual void handle_measure(unsigned long now);

  virtual void handle_safety(unsigned long now);

  virtual void handle_pid(unsigned long now);

  virtual void handle_reflow(unsigned long now) = 0;

  virtual void handle_calibration(unsigned long now);
};

#endif

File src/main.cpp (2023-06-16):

/**
 *  Copyright (C) 2018  foxis (Andrius Mikonis <andrius.mikonis@gmail.com>)
 *
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
 *  You should have received a copy of the GNU General Public License
 *  along with this program.  If not, see <http://www.gnu.org/licenses/>.
 **/

#include <ESPAsyncWebServer.h>
#include <SPIFFSEditor.h>
#include "ReflowController_v1.h"
#include <ArduinoJson.h>
#include "AsyncJson.h"
#include "Config.h"
#include <Adafruit_GFX.h>
#include <Adafruit_SSD1306.h>
#include <esp_task_wdt.h>

#define OLED_RESET 4        // Reset pin # (or -1 if sharing Arduino reset pin)
#define SCREEN_ADDRESS 0x3D ///< See datasheet for Address; 0x3D for 128x64, 0x3C for 128x32

AsyncWebServer server(80);
AsyncWebSocket ws("/ws");
AsyncEventSource events("/event");
ControllerBase *controller = NULL;
AsyncWebSocketClient *_client = NULL;
Config config("/config.json", "/profiles.json");
Adafruit_SSD1306 display(128, 64, &Wire, -1);

void textThem(const char *text)
{
  int tryId = 0;
  for (int count = 0; count < ws.count();)
  {
    if (ws.hasClient(tryId))
    {
      ws.client(tryId)->text(text);
      count++;
    }
    tryId++;
  }
}

void textThem(const String &text)
{
  textThem(text.c_str());
}

void textThem(JsonObject &root, AsyncWebSocketClient *client)
{
  String json;
  root.printTo(json);

  if (client != NULL)
    client->text(json);
  else
    textThem(json);
}

void textThem(JsonObject &root)
{
  textThem(root, NULL);
}

void send_reading(float reading, float target, float time, AsyncWebSocketClient *client, bool reset)
{
  S_printf("Sending readings...");

  StaticJsonBuffer<200> jsonBuffer;
  JsonObject &root = jsonBuffer.createObject();

  JsonObject &data = root.createNestedObject("readings");
  JsonArray &times = root.createNestedArray("times");
  JsonArray &readings = root.createNestedArray("readings");
  JsonArray &targets = root.createNestedArray("targets");

  times.add(time);
  readings.add(reading);
  targets.add(target);
  data["reset"] = reset;

  textThem(root);
}

void setupController(ControllerBase *c)
{
  S_printf("Controller setup..");

  // report messages
  c->onMessage([](const char *msg)
               {
		StaticJsonBuffer<200> jsonBuffer;
		JsonObject &root = jsonBuffer.createObject();
		root["message"] = msg;
		textThem(root); });

  c->onHeater([](bool heater)
              {
		S_printf("Heater: %s", heater ? "on" : "off");
		StaticJsonBuffer<200> jsonBuffer;
		JsonObject &root = jsonBuffer.createObject();
		root["heater"] = heater;
		textThem(root); });

  // report readings
  c->onReadingsReport([](const std::vector<ControllerBase::Temperature_t> &readings, unsigned long elapsed)
                      { send_reading(controller->log_to_temperature(readings[readings.size() - 1]), controller->target(), elapsed / 1000.0, NULL, readings.size() == 1); });

  // report mode change
  c->onMode([](ControllerBase::MODE_t last, ControllerBase::MODE_t current)
            {
		S_printf("Change mode: from %s to %s", controller->translate_mode(last), controller->translate_mode(current));
		StaticJsonBuffer<200> jsonBuffer;
		JsonObject &root = jsonBuffer.createObject();
		root["mode"] = controller->translate_mode(current);

		textThem(root); });
  c->onStage([](const char *stage, float target)
             {
		S_printf("Reflow stage: %s", stage);
		StaticJsonBuffer<200> jsonBuffer;
		JsonObject &root = jsonBuffer.createObject();
		root["stage"] = stage;
		root["target"] = target;
		textThem(root); });

  controller = c;
  S_printf("Controller setup DONE");
}

void send_data(AsyncWebSocketClient *client)
{
  S_printf("Sending all data...");
  std::vector<ControllerBase::Temperature_t>::iterator I = controller->readings().begin();
  std::vector<ControllerBase::Temperature_t>::iterator end = controller->readings().end();
  DynamicJsonBuffer jsonBuffer;
  JsonObject &root = jsonBuffer.createObject();
  JsonArray &times = root.createNestedArray("times");
  JsonArray &readings = root.createNestedArray("readings");
  JsonArray &targets = root.createNestedArray("targets");
  root["reset"] = true;
  root["message"] = "INFO: Connected!";
  root["mode"] = controller->translate_mode();
  root["target"] = controller->target();
  root["profile"] = controller->profile();
  root["stage"] = controller->stage();
  root["heater"] = controller->heater();

  float seconds = 0;
  while (I != end)
  {
    times.add(seconds);
    readings.add(controller->log_to_temperature(*I));
    targets.add(controller->target());
    seconds += config.reportInterval / 1000.0;
    I++;
  }

  textThem(root, client);
}

void setup()
{
  Serial.begin(115200);
  Wire.begin(I2C_SCL, I2C_SDA, 100000);
  pinMode(18, OUTPUT);
  pinMode(23, OUTPUT);
  SPIFFS.begin();

  if (!display.begin(SSD1306_SWITCHCAPVCC, SCREEN_ADDRESS))
  {
    Serial.println(F("SSD1306 allocation failed"));
    for (;;)
      ; // Don't proceed, loop forever
  }

  display.setRotation(2);
  display.clearDisplay();
  display.setTextColor(1);

  display.display();

  config.load_config();

  display.clearDisplay();
  display.setCursor(0, 0);
  display.setTextSize(1);
  display.println("");

  display.setCursor(0, 12);
  display.setTextSize(4);
  display.println("");

  display.setCursor(0, 64 - 16);
  display.setTextSize(2);
  display.println("config ok");
  display.display();

  config.load_profiles();
  display.clearDisplay();
  display.setCursor(0, 0);
  display.setTextSize(1);
  display.println("");

  display.setCursor(0, 12);
  display.setTextSize(4);
  display.println("");

  display.setCursor(0, 64 - 16);
  display.setTextSize(2);
  display.println("profile ok");
  display.display();

  WiFi.persistent(false);
  WiFi.begin(WIFI_SSID, WIFI_PASSWORD);
  int count = 0;
  while (WiFi.status() != WL_CONNECTED)
  {
    String pr = "Wifi";
    for (int i = 0; i < count; i++)
    {
      pr = pr + "+";
    }
    display.setTextWrap(true);
    display.clearDisplay();
    display.setCursor(0, 0);
    display.setTextSize(1);
    display.println(pr);
    Serial.println(pr);
    display.display();

    delay(500);
    count++;
  }
  display.setTextWrap(false);
  Serial.println(WiFi.localIP());

  server.addHandler(&ws);
  server.addHandler(&events);
  server.serveStatic("/", SPIFFS, "/web").setDefaultFile("index.html");
  // Heap for general Servertest
  server.on("/heap", HTTP_GET, [](AsyncWebServerRequest *request)
            { request->send(200, "text/plain", String(ESP.getFreeHeap())); });
  server.on("/profiles", HTTP_GET, [](AsyncWebServerRequest *request)
            {
		AsyncWebServerResponse *response = request->beginResponse(SPIFFS, "/profiles.json");
		//request->send(SPIFFS, "/profiles.json");
		response->addHeader("Access-Control-Allow-Origin", "*");
		response->addHeader("Access-Control-Allow-Methods", "GET");
		response->addHeader("Content-Type", "application/json");
		request->send(response); });
  server.on("/config", HTTP_GET, [](AsyncWebServerRequest *request)
            {
		AsyncWebServerResponse *response = request->beginResponse(SPIFFS, "/config.json");
		//request->send(SPIFFS, "/profiles.json");
		response->addHeader("Access-Control-Allow-Origin", "*");
		response->addHeader("Access-Control-Allow-Methods", "GET");
		response->addHeader("Content-Type", "application/json");
		request->send(response); });
  server.on(
      "/profiles", HTTP_POST, [](AsyncWebServerRequest *request) {}, NULL, [](AsyncWebServerRequest *request, uint8_t *data, size_t len, size_t index, size_t total)
      {
		config.save_profiles(request, data, len, index, total);
		config.load_profiles(); });
  server.on(
      "/config", HTTP_POST, [](AsyncWebServerRequest *request) {}, NULL, [](AsyncWebServerRequest *request, uint8_t *data, size_t len, size_t index, size_t total)
      { config.save_config(request, data, len, index, total); });
  server.on("/calibration", HTTP_GET, [](AsyncWebServerRequest *request)
            {
		AsyncWebServerResponse *response = request->beginResponse(200, "application/json", controller->calibrationString());
		response->addHeader("Access-Control-Allow-Origin", "*");
		response->addHeader("Access-Control-Allow-Methods", "GET");
		request->send(response); });
  server.onNotFound(
      [](AsyncWebServerRequest *request)
      { request->send(404); });

  ws.onEvent([](AsyncWebSocket *server, AsyncWebSocketClient *client, AwsEventType type, void *arg, uint8_t *data, size_t len)
             {
		if (type == WS_EVT_DATA) {
			char cmd[256] = "";
			memcpy(cmd, data, min(len, sizeof(cmd) - 1));

			if (strcmp(cmd, "WATCHDOG") == 0) {
			} else if (strncmp(cmd, "profile:", 8) == 0) {
				controller->profile(String(cmd + 8));
				sprintf(cmd, "{\"profile\": \"%s\"}", controller->profile().c_str());
				textThem(cmd);
			} else if (strcmp(cmd, "ON") == 0) {
				controller->mode(ControllerBase::ON);
			} else if (strcmp(cmd, "REBOOT") == 0) {
				ESP.restart();
			} else if (strcmp(cmd, "CALIBRATE") == 0) {
				controller->mode(ControllerBase::CALIBRATE);
			} else if (strcmp(cmd, "TARGET_PID") == 0) {
				controller->mode(ControllerBase::TARGET_PID);
			} else if (strcmp(cmd, "REFLOW") == 0) {
				controller->mode(ControllerBase::REFLOW);
				delay(2000);
			} else if (strcmp(cmd, "OFF") == 0) {
				controller->mode(ControllerBase::OFF);
			} else if (strcmp(cmd, "COOLDOWN") == 0) {
				controller->mode(ControllerBase::CALIBRATE_COOL);
			} else if (strcmp(cmd, "CURRENT-TEMPERATURE") == 0) {
				unsigned long now = millis();
				send_reading(controller->measure_temperature(now), controller->target(), controller->elapsed(now)/1000.0, NULL, false);
			} else if (strncmp(cmd, "target:", 7) == 0) {
				controller->target(max(0, min(atoi(cmd + 7), MAX_TEMPERATURE)));
				sprintf(cmd, "{\"target\": %.2f}", controller->target());
				textThem(cmd);
			}
		} else if (type == WS_EVT_CONNECT) {
			send_data(client);
			S_printf("Connected...");
		} else if (type == WS_EVT_DISCONNECT) {
			S_printf("Disconnected...");
			//controller->mode(ControllerBase::ERROR_OFF);
		} });

  server.begin();
  setupController(new ReflowController(config, display));

  S_printf("Server started..");
  display.clearDisplay();

  esp_task_wdt_init(3, true); // enable panic so ESP32 restarts
  esp_task_wdt_add(NULL);
}

int count = 0;
void loop()
{
  digitalWrite(23, HIGH);
  digitalWrite(18,LOW);
  esp_task_wdt_reset();
  unsigned long now = millis();
  controller->loop(now);
}

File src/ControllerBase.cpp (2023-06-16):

/**
 *  Copyright (C) 2018  foxis (Andrius Mikonis <andrius.mikonis@gmail.com>)
 *
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
 *  You should have received a copy of the GNU General Public License
 *  along with this program.  If not, see <http://www.gnu.org/licenses/>.
 **/

#include "ControllerBase.h"


ControllerBase::ControllerBase(Config &cfg, Adafruit_SSD1306 &display) : config(cfg),
															pidTemperature(&_temperature, &_target_control, &_target, .5 / DEFAULT_TEMP_RISE_AFTER_OFF, 5.0 / DEFAULT_TEMP_RISE_AFTER_OFF, 4 / DEFAULT_TEMP_RISE_AFTER_OFF, DIRECT),
															aTune(&_temperature, &_target_control, &_target, &_now, DIRECT),
															thermocouple(thermoCLK, thermoCS, thermoDO)
{
	this->display = display;
	_readings.reserve(15 * 60);

	_calP = .5 / DEFAULT_TEMP_RISE_AFTER_OFF;
	_calD = 5.0 / DEFAULT_TEMP_RISE_AFTER_OFF;
	_calI = 4 / DEFAULT_TEMP_RISE_AFTER_OFF;

	pidTemperature.SetSampleTime(config.measureInterval * 1000);
	pidTemperature.SetMode(AUTOMATIC);
	pidTemperature.SetOutputLimits(0, 1);

	_setPinMode(RELAY, OUTPUT);

	_setPinValue(RELAY, LOW);

	_mode = _last_mode = INIT;
	_temperature = 0;
	_target = DEFAULT_TARGET;
	_onMessage = NULL;
	_onMode = NULL;
	_onReadingsReport = NULL;
	_locked = false;
	_last_heater_on = 0;

	_heater = _last_heater = false;

	// TODO sound

	// TODO tone(BUZZER_A, 440, 100);

	setPID("default");

	_temperature = _read_temperature();

	S_printf("Current temperature: %f\n", _temperature);
	_readings.push_back(temperature_to_log(_temperature));
}

void ControllerBase::loop(unsigned long now)
{

	if (now - last_m > config.measureInterval)
	{
		if (_last_mode == _mode && _mode >= ON)
		{
			handle_measure(now);
		}else {
			_read_temperature();
			last_m = now;
		}
	}

	switch (_mode)
	{
	case INIT:
		callMessage("%s Initialized and ready", name());
		line1 = "init";
		mode(OFF);
		break;
	case ON:
		line1 = "ON";
		// callMessage("WARNING: Heater is on until turned off");
		_heater = true;
		break;
	case ERROR_OFF:
	case OFF:
		line1 = "OFF";
		// callMessage("WARNING: Heater is on until turned off");
		_heater = false;
		break;
	case TARGET_PID:
		line1 = "TARGET_PID";
		handle_pid(now);
		break;
	case REFLOW:
		line1 = "REFLOW";
		handle_reflow(now);
		break;
	case CALIBRATE:
		line1 = "CALIBRATE";
		handle_calibration(now);
		break;
	case CALIBRATE_COOL:
	case REFLOW_COOL:
		line1 = "COOLdown";
		_heater = false;
		if (_temperature < SAFE_TEMPERATURE)
		{
			callMessage("INFO: Temperature has reached safe levels (<%.2f*C). Max temperature: %.2f", (float)SAFE_TEMPERATURE, (float)_CALIBRATE_max_temperature);
			mode(OFF);
		}
	}

	handle_mode(now);

	handle_safety(now);

	_setPinValue(RELAY, _heater);

	if (_onHeater && _heater != _last_heater)
		_onHeater(_heater);
	_last_heater = _heater;

	draw();
}

float ControllerBase::_read_temperature()
{
	float tmp = thermocouple.readCelsius();
	line2 = String((int)round(tmp)) + char(0xf7);
	return tmp;
}

void ControllerBase::_setPinMode(int pin, int mode)
{
	pinMode(pin, mode);
}

void ControllerBase::_setPinValue(int pin, int value)
{
	digitalWrite(pin, value);
}

PID &ControllerBase::setPID(float P, float I, float D)
{
	resetPID();
	pidTemperature.SetTunings(P, I, D);
	return pidTemperature;
}

PID &ControllerBase::setPID(const String &name)
{
	if (config.pid.find(name) == config.pid.end())
	{
		callMessage("WARNING: No PID named '%s' found!!", name.c_str());
		return pidTemperature;
	}
	else
	{
		callMessage("INFO: Setting PID to '%s'.", name.c_str());
		return setPID(config.pid[name].P, config.pid[name].I, config.pid[name].D);
	}
}

void ControllerBase::resetPID()
{
	pidTemperature.Reset();
}

String ControllerBase::calibrationString()
{
	char str[64] = "";
	sprintf(str, "[%f, %f, %f]", _calP, _calI, _calD);
	return str;
}

const char *ControllerBase::translate_mode(MODE_t mode)
{
	MODE_t m = mode == UNKNOWN ? _mode : mode;
	switch (m)
	{
	case INIT:
		return "Init";
		break;
	case ON:
		return "ON";
		break;
	case OFF:
		return "OFF";
		break;
	case CALIBRATE:
		return "Calibrating 1";
		break;
	case TARGET_PID:
		return "Keep Target";
		break;
	case CALIBRATE_COOL:
		return "Cooldown";
		break;
	case ERROR_OFF:
		return "Error";
		break;
	case REFLOW:
		return "Reflow";
		break;
	case REFLOW_COOL:
		return "Cooldown";
		break;
	default:
		return "default";
	}
}

ControllerBase::Temperature_t ControllerBase::temperature_to_log(float t)
{
	return t; // TODO: convert to 16bit fixed point
}

float ControllerBase::log_to_temperature(ControllerBase::Temperature_t t)
{
	return isnan(t) ? 0.0 : t;
}

float ControllerBase::measure_temperature(unsigned long now)
{
	if (now - last_m > config.measureInterval * 1.1)
	{
		last_m = now;
		return temperature(_read_temperature());
	}
	else
		return temperature();
}
unsigned long ControllerBase::elapsed(unsigned long now)
{
	return now - _start_time;
}

void ControllerBase::callMessage(const char *format, ...)
{
	char buffer[512];
	va_list args;
	va_start(args, format);
	vsnprintf(buffer, sizeof(buffer), format, args);
	if (_onMessage)
		_onMessage(buffer);
	Serial.println(buffer);
	va_end(args);
}

void ControllerBase::reportReadings(unsigned long now)
{
	if (_onReadingsReport)
		_onReadingsReport(_readings, now);
}

void ControllerBase::handle_mode(unsigned long now)
{
	if (_last_mode <= OFF && _mode > OFF)
	{
		_start_time = now;
		_temperature = _read_temperature();
		pidTemperature.Reset();
		_readings.clear();
		_readings.push_back(temperature_to_log(_temperature));
		reportReadings(now - _start_time);
		last_m = now;
		last_log_m = now;
		_avg_rate = 0;

		if (_mode == CALIBRATE)
		{
			_target_control = config.tuner_init_output; // initial output
			//_temperature = _target;		// target temperature
			aTune.Cancel();								   // just in case
			aTune.SetNoiseBand(config.tuner_noise_band);   // noise band +-1*C
			aTune.SetOutputStep(config.tuner_output_step); // change output +-.5 around initial output
			aTune.SetControlType(config.tuner_id);
			aTune.SetLookbackSec(config.measureInterval * 100);
			aTune.SetSampleTime(config.measureInterval);

			_now = now;
			aTune.Runtime(); // initialize autotuner here, as later we give it actual readings
		}
		else if (_mode == TARGET_PID)
		{
			setPID("default");
			pidTemperature.Reset();
		}
	}
	else if (_mode <= OFF && _last_mode > OFF)
	{
		_temperature = _read_temperature();
		_readings.push_back(temperature_to_log(_temperature));
		if (_last_mode == REFLOW || _last_mode == REFLOW_COOL)
			setPID("default");
		reportReadings(now - _start_time);
	}
	if (_onMode && _last_mode != _mode)
	{
		_onMode(_last_mode, _mode);
	}
	_last_mode = _mode;
}
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

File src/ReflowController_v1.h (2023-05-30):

/*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
 *  You should have received a copy of the GNU General Public License
 *  along with this program.  If not, see <http://www.gnu.org/licenses/>.
 **/

#ifndef REFLOWCONTROLLER_v1_H
#define REFLOWCONTROLLER_v1_H

#include <ArduinoJson.h>
#include "ControllerBase.h"

class ReflowController : public ControllerBase
{
  unsigned long _stage_start;
  double _start_temperature;
  Config::stages_iterator current_stage;
  Config::profiles_iterator current_profile;

public:
  ReflowController(Config &cfg, Adafruit_SSD1306 &display) : ControllerBase(cfg, display)
  {
    _stage_start = 0;
    current_profile = config.profiles.end();
    line3 = WiFi.localIP().toString();
  }

  virtual void handle_reflow(unsigned long now)
  {
    if (current_profile == config.profiles.end())
    {
      callMessage("ERROR: No Profile in reflow mode!");
      mode(ERROR_OFF);
      return;
    } // else if (current_stage == current_profile->second.stages.end())
      // line3 = "Finished";
      // draw();
      // return;
    float direction = current_stage->target >= _start_temperature ? 1 : -1;
    if (direction * (temperature() - current_stage->target) > 0 && _stage_start == 0)
    {
      _stage_start = now;
      if (current_stage->rate <= 0)
        target(current_stage->target);
      resetPID();
      callMessage("INFO: Stage reached, waiting for %f seconds...", current_stage->stay);
      line3 = current_stage->name;
      draw();
    }
    else if (_stage_start != 0 && now - _stage_start > current_stage->stay * 1000)
    {
      stage(++current_stage);
    }

    handle_pid(now);
  }

  virtual const char *name() { return "Reflow Controller v1.0"; }

  virtual void handle_measure(unsigned long now)
  {
    ControllerBase::handle_measure(now);
    if (ControllerBase::mode() == REFLOW)
    {
      handle_target(avg_rate());
    }
  }

  virtual void interpolate_target(float direction)
  {
    float next_temperature = target() + direction * current_stage->rate * config.measureInterval / 1000.0;
    float target_cap = current_stage->target;
    float T = direction > 0 ? min(next_temperature, target_cap) : max(next_temperature, target_cap);
    // callMessage("DEBUG: target: d=%f     t=%f    T=%f", direction, next_temperature, T);
    target(T);
    // resetPID();
  }
  virtual void handle_target(float current_rate)
  {
    if (current_profile != config.profiles.end()                 // profile set
        && current_stage != current_profile->second.stages.end() // stage set
        && current_stage->rate > 0                               // rate set
        && abs(current_rate) <= current_stage->rate)
    { // current average rate is within limits

      float direction = target() <= current_stage->target ? 1 : -1;

      if (direction * (temperature() - current_stage->target) < 0 // haven't reached stage target yet
          && (direction * (temperature() - target()) > 0 || abs(current_rate) < current_stage->rate))
      { // reached interpolated target
        interpolate_target(direction);
      } /* else if (current_profile != config.profiles.end()
          && current_stage != current_profile->second.stages.end()
          && current_stage->rate > 0
          && abs(current_rate) > current_stage->rate) {
          TODO: override _current_control
      } */
    }
  }

  // TODO:
  // * sanity checks
  // * profile check
  // * load profile on reflow start
  virtual MODE_t mode(MODE_t m)
  {
    if (m != REFLOW)
    {
      return ControllerBase::mode(m);
    }

    if (current_profile != config.profiles.end())
    {
      stage(current_profile->second.stages.begin());
      return ControllerBase::mode(m);
    }
    return ControllerBase::mode(OFF);
  }

  virtual const String &profile(const String &name)
  {
    Config::profiles_iterator p = config.profiles.find(name);
    if (p != config.profiles.end())
    {
      if (p->second.stages.begin() == p->second.stages.end())
      {
        callMessage("ERROR: Profile '%s' has no stages!", name.c_str());
        return ControllerBase::profile();
      }
      mode(OFF);
      current_profile = p;
      current_stage = p->second.stages.begin();
      stage(current_stage);
      callMessage("INFO: Profile set to '%s'", current_profile->second.name.c_str());
      return ControllerBase::profile(name);
    }
    else
    {
      mode(ERROR_OFF);
      callMessage("ERROR: No such profile '%s' found!", name.c_str());
      return ControllerBase::profile();
    }
  }

  virtual const String &profile()
  {
    if (current_profile != config.profiles.end())
      return current_profile->second.name;
    else
      return ControllerBase::profile();
  }

  virtual const String &stage()
  {
    if (current_profile != config.profiles.end())
    {
      return current_stage->name;
    }
    else
      return ControllerBase::stage();
  }

  virtual const String &stage(Config::stages_iterator stage)
  {
    Config::stages_iterator last_stage = current_stage;
    current_stage = stage;

    if (current_stage != last_stage)
      callMessage("INFO: Stage '%s' finished.", last_stage->name.c_str());
    if (stage != current_profile->second.stages.end())
    {
      setPID(stage->pid);
      _stage_start = 0;
      _start_temperature = measure_temperature(millis());
      if (stage->rate > 0)
      {
        if (last_stage == current_stage)
        {
          target(_start_temperature);
        }
        else
          target(last_stage->target);
      }
      else
      {
        target(stage->target);
      }
      if (_onStage)
        _onStage(stage->name.c_str(), (float)stage->target);
      line3 = stage->name;
      draw();
      return ControllerBase::stage(stage->name);
    }
    else
    {
      mode(REFLOW_COOL);
      target(20);
      if (_onStage)
        _onStage("DONE", target());
      line3 = "DONE";
      draw();
      return ControllerBase::stage();
    }
  }
};

#endif

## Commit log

2019-02-09 switched project to use simple thermistor and no io extender
2019-02-10 buzzer check, pcb design
    [IRM-05-5--3DModel-STEP-56544.STEP, MrReflow.kicad_pcb, MrReflow.sch]
2019-02-10 layout adjustments
    [MrReflow.kicad_pcb]
2019-02-10 initial production run export
    [MrReflow-B.Cu.gbr, MrReflow-B.Paste.gbr, MrReflow-B.SilkS.gbr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]
2019-02-20 fixed thermistor calibration
2022-05-18 modernized pcb with esp32 modernized webapp
    [IRM-05-5--3DModel-STEP-56544.STEP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]
2023-05-24 Update c_cpp_properties.json, MrReflow.kicad_prl, MrReflow.kicad_pro, and 3 more files
2023-06-25 Update README.md, favicon.png, accept.png, and 64 more files
    [ReflowESP.dsn, ReflowESP.kicad_pcb, ReflowESP.kicad_sch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]
2023-08-21 Update c_cpp_properties.json, PCB_by_kien242.kicad_pcb, PCB_by_kien242.kicad_prl, and 155 more files
    [MrReflow-B_Cu.gbr, MrReflow-B_Mask.gbr, MrReflow-B_Silkscreen.gbr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]

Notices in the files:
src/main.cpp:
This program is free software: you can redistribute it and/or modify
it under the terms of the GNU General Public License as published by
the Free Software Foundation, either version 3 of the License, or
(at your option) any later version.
